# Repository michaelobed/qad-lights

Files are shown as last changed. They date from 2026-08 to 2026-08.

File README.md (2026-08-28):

# Quick-and-Dirty Lights

## What is it?

A quick-and-dirty WiFi-configurable RGB LED driver so I can make my wardrobe all pretty inside.

## Why?

I use RGB LED strips a lot, [as you could probably tell](https://github.com/michaelobed/rgb-switcher), and I can't be bothered with (re)programming an Arduino every time I want to change something subtle, so I bashed something together that lets me change everything I would want to remotely. (I say "bashed", but it took me exactly a week. Oh well!)

## Overview

### Concept

The concept is simple: A microcontroller drives three channels of LEDs, one for red, one for green and one for blue. They either stay on permanently, or turn on when switches are activated in different ways. If you want to change how it operates, you access its web portal and fiddle. That's it!

### Why didn't you build rgb-switcher this way?

Because I am a silly-billy who didn't think that through and thought that retroactively adding web configuration using _an entire other daughterboard_ would be a great idea. Maybe I'll do a v2 rearchitected around the ESP32 when life demands less of me. 😂

### The core system

There isn't much to say on this project really, other than that it's based around the ubiquitous ESP32 chip. It has a decent HAL, simple APIs for key-value storage, WiFi and a HTTP server (not HTTPS for this project - more on that later). Add to that the easy-to-configure PWM driver for LED control and you have a browser-controllable RGB LED driver. Tada! 🎉

### PWM

As I mentioned earlier, this project configures 3 GPIOs as individually controllable PWM outputs, with 8-bit resolution per channel for what is effectively 24-bit colour*. The PWM is actually capable of even more resolution than that, but 8-bit is all the discernible colour difference I need I think. The PWM driver even has built-in hardware fade support, so of course I was going to take advantage of that! It wouldn't have been hard to roll my own if it came down to it, like I did in the hitherto hinted at rgb-switcher project, but it came as a nice surprise.

*: In practice, the resolution is a _lot_ less than that, because big RGB LEDs aren't that great at colour accuracy from experience.

### GPIO

The system currently supports two GPIO inputs, representing reed switches which'll go on my wardrobe doors. It'll turn on when either switch is active or when both switches are active, depending on settings. It also supports both normally open and normally closed orientations.

I normally like to set up switch GPIOs to use the internal pull-up of a microcontroller and connect the other end to GND, but for some really weird reason, that doesn't work here, so I've instead pulled them down and tied the other end to +3V3. It feels icky and perverse, but it works at least.

### WiFi

This is the thing the ESP32 really shines at. It has a built-in 2.4GHz WiFi modem, complete with radio circuitry and, depending on which module you use, often has a built-in ~~antenna~~ aerial 🇬🇧. By default, it boots into access point mode, meaning you connect to _it_ to access its web portal. You can later configure it to connect to your own network for easier access if you so desire.

### HTTP server

This is easily the thing that took the longest, partly because PWM and WiFi are easy and because I really don't do any web coding! I used the actually rather good built-in ESP HTTP Server library, slapped some pages together in HTML and Javascript, then added Websockets support for good measure, so that config changes and RGB sliders all work in realtime.

I almost forgot to mention the lack of HTTP**S** support: I believe you need to supply your own .pem certificate to use that, and for this simple use case that will never see the light of the Internet, I couldn't be bothered with that. It's a good thing to consider, though, especially given that the password to your WiFi network of choice is otherwise supplied over an unencrypted connection in plaintext using the HTTP POST method. A man-in-the-middle attack is possible I suppose, but improbable and impractical, so I'm not too worried.

### Over-the-air firmware updates

The system supports over-the-air firmware updates, or at least firmware updates that don't require you to dismantle your setup and connect a USB cable. For now it's a bit slow and doesn't have per-packet checksumming, so it can fail from time to time, but never in a way that bricks the ESP32 thanks to the implementation of two dedicated OTA partitions.

To use it, navigate to _Update firmware_, then select a .bin file, then click _OK_. If successful, the system will automatically restart and boot from the new firmware image.

### Sleep

The system supports going to sleep when the lights have been off for some period of time to save power. While sleep can be used in setups with normally-closed switches, it isn't recommended as it will contribute to a slightly higher current draw (~15mA more from informal tests).

> [!WARNING]
> The network will not reconnect when waking up from sleep. To have the ESP32 reconnect to the network to allow web configuration, you must use the RESET/EN pin or power cycle it. There will then be a minute-long holdoff period, after which the ESP32 will sleep if there is no web UI connection.

## Final notes

I should point out that I developed this against an ESP-WROOM-32 module sitting on an ESP32-DevKitC board, which is probably really old! I'm sure the code is device-agnostic enough to easily get working on other modules, or even a custom board, but I've done no testing on this. Your mileage may vary, I guess.

I've included a very rough schematic as a guide on how I put this together. I didn't really use a 5V voltage regulator in practice since the dev board was powered via USB for ease of debugging. I pretty much copied the power circuitry from rgb-switcher, and I see no reason for it not to work here given the similar power domain requirements.

I did have a weird issue where the red LED was quite a bit dimmer than green and blue, even after swapping GPIOs around a bit. This ended up being the use of IRF540 mosfets in the end - they barely conduct with the gate-source voltage of 3.3V. I presume the difference in forward voltage of green/blue LEDs vs. red LEDs also contributed to this. I swapped them out for TIP41C darlington BJTs, which I've also used in the past to drive RGB LED strips, though they waste a bit more power doing it from my experience. The fades between the channels are also no longer uniform annoyingly, but at least full white looks white now instead of blue! I didn't get to try the IRF540s with other LED strips, but I'm sure this is a more universal solution than what I had.

As always, I'm releasing this under the MIT license so people can fork the repo, modify the code, sell a product based around it or whatever else. I'm just happy this exists and I can stop writing an entire LED driver when I need one!

## What next?

Since I did bash this together, there are a number of things that are missing or that I'm not completely happy with (in no particular order):

- ~~**Over-the-air firmware update support**. I've provided a partition or two for that, but I've never looked into doing it on the ESP32. It seems simple enough to do, however. Maybe one of you can do it... 😏~~
- **Support for a variable number of switches**. In theory, the logic I have in place makes that feasible, and the `Config` class can easily be extended to allow both the number of switches and their GPIO assignments to be configurable.
- **Make the UI less boring**? This one's more of a maybe since I don't really care that much and just wanted it working, but perhaps a square that changes colours next to the RGB sliders could be cool, albeit more colour accurate than the lights will ever be.
- ~~**Sleep mode**! These should be able to go to sleep when sitting there for ages doing nothing, then wake up and drive the LEDs when the door is opened. This should be easy enough to set up as a wake-up interrupt of some kind.~~
- **Configurable fade time**. This was actually supposed to be in the `Config` class too, but I just haven't gotten around to it.
- **Improve OTA updates**. This is mostly finding ways to increase the chunk size to make updates go faster, as well as adding a per-chunk checksum so we can retry chunks that get corrupted in transit.

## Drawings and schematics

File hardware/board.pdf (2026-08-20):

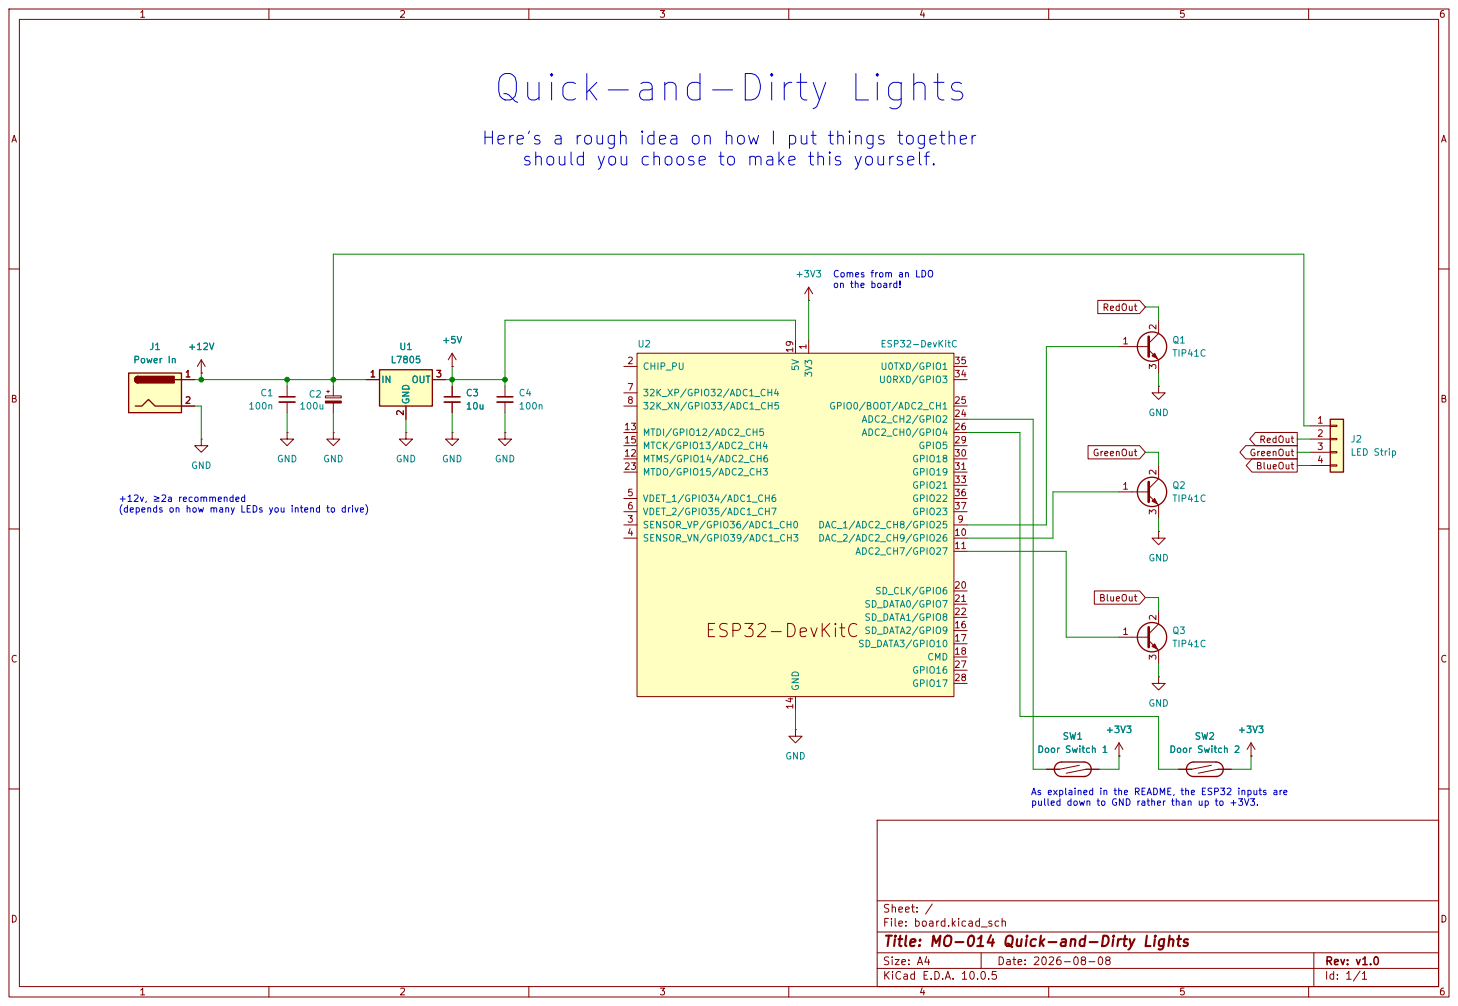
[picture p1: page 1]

Here's a rough idea on how I put things together
should you choose to make this yourself. Comes from an LDO

on the board! +12v, ≥2a recommended

LED Strip +3V3 SW2 Door Switch 2 C2

Sheet: /
File: board.kicad_sch
Title: MO-014 Quick-and-Dirty Lights

Size: A4 | Rev: v1.0
KiCad E.D.A. 10.0.5 | Id: 1/1

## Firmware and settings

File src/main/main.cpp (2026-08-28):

//
//  main.cpp
//  qad-lights
//
//  Created by michaelobed on 29/07/2026.
//  
//  Copyright © 2026 Michael Obed.

#include "Config.hpp"
#include "esp_log.h"
#include "freertos/FreeRTOS.h"
#include "Http.hpp"
#include "Lighting.hpp"
#include "Network.hpp"
#include "Sleep.hpp"
#include "SwitchIO.hpp"
#include "freertos/task.h"
#include "Update.hpp"

static Config& config = Config::GetInstance();
static Http& http = Http::GetInstance();
static Lighting& lighting = Lighting::GetInstance();
static volatile bool lightingState = false;
static volatile bool lightingStateLast = false;
static Network& network = Network::GetInstance();
static Sleep& sleep = Sleep::GetInstance();
static SwitchIO& switchIo = SwitchIO::GetInstance();
static TaskHandle_t switchIOTaskHandle = nullptr;
static Update& update = Update::GetInstance();

static void errorHandler();
static void periodicTask(void* arg);

extern "C" void app_main()
{
    esp_err_t err = ESP_OK;
    bool isSTA = false;

    /* Check for and validate any new OTA images. */
    err = update.Check();
    if(err != ESP_OK)
    {
        ESP_LOGE(__func__, "Could not validate image (%d)!", err);
        errorHandler();
    }

    /* Initialise a default event loop. */
    err = esp_event_loop_create_default();
    if(err != ESP_OK)
    {
        /* We couldn't initialise the default event loop. This is even worse. Freak out! */
        ESP_LOGE(__func__, "Could not init event loop (%d)!", err);
        errorHandler();
    }

    /* Initialise NVS storage. */
    err = config.InitStorage();
    if(err != ESP_OK)
    {
        ESP_LOGE(__func__, "Could not init config storage (%d)!", err);
        errorHandler();
    }

    /* Load the config (or create one if it doesn't exist). */
    err = config.Load();
    if(err != ESP_OK)
    {
        ESP_LOGW(__func__, "Config did not exist or was corrupted. Saving afresh...");
        config.Save();
    }
    else ESP_LOGI(__func__, "Config loaded successfully.");

    /* Initialise switches and create background task. */
    err = switchIo.Configure();
    if(err != ESP_OK)
    {
        ESP_LOGE(__func__, "Could not configure switches (%d)!", err);
        errorHandler();
    }
    xTaskCreate(periodicTask, "SwitchIO", 2048, nullptr, tskIDLE_PRIORITY, &switchIOTaskHandle);

    /* Initialise the lighting driver. */
    err = lighting.Init();
    if(err != ESP_OK)
    {
        ESP_LOGE(__func__, "Could not init lighting driver (%d)!", err);
        errorHandler();
    }

    /* Start the WiFi! */
    isSTA = (config.GetConfigData("networkIsSTA") == 1);
    if(isSTA)
    {
        err = network.InitSTA();
        if(err != ESP_OK)
        {
            ESP_LOGW(__func__, "Could not start WiFi connection to network (%d)! Reverting to access point mode.", err);
            isSTA = false;
        }
        else ESP_LOGI(__func__, "WiFi connection to network started successfully.");
    }

    if(!isSTA)
    {
        err = network.InitAP();
        if(err != ESP_OK)
        {
            ESP_LOGE(__func__, "Could not start WiFi access point (%d)!", err);
            errorHandler();
        }
        else ESP_LOGI(__func__, "WiFi access point started.");
    }

    /* Get HTTP server going. */
    err = http.Init();
    if(err != ESP_OK)
    {
        ESP_LOGE(__func__, "Could not start HTTP server (%d)!", err);
        errorHandler();
    }
    else ESP_LOGI(__func__, "HTTP server started.");

    /* Start a default sleep timer. This won't take effect if we're configured to never sleep. */
    sleep.TimerStartDefault();

    ESP_LOGI(__func__, "Init done! Running main loop...");

    while(true)
    {
        /* Delay so main loop doesn't choke for watchdog reasons. */
        vTaskDelay(100 / portTICK_PERIOD_MS);
    }
}

__noreturn void errorHandler()
{
    /* Do nothing forever. */
    while(true);
}

void Restart()
{
    constexpr uint32_t delayUs = 3000000UL;

    esp_rom_delay_us(delayUs);
    ESP_LOGW(__func__, "*** RESET!!! ***");
    vTaskDelete(switchIOTaskHandle);
    lighting.DeInit();
    if(network.IsRunning())
        network.DeInit();

    esp_restart();
}

void periodicTask(void* arg)
{
    bool lightingStateChanged = false;

    /* Fire every 100ms. */
    while(true)
    {
        /* Handle changes in lighting state based on switch state. */
        lightingState = switchIo.Update();
        lightingStateChanged = (lightingState != lightingStateLast);
        if(lightingStateChanged)
        {
            ESP_LOGI(__func__, "Lighting change detected!");
            lighting.SetState(lightingState);
            lightingStateLast = lightingState;

            /* Start/stop the sleep timer according to the lighting state. */
            if(lightingState)
                sleep.TimerStop();
            else sleep.TimerStart();
        }

        /* Finally, check if we should be sleeping (and sleep if true). */
        sleep.Update();

        vTaskDelay(100 / portTICK_PERIOD_MS);
    }
}

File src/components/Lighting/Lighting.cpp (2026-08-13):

//
//  Lighting.cpp
//  qad-lights
//
//  Created by michaelobed on 29/07/2026.
//  
//  Copyright © 2026 Michael Obed.

#include "Config.hpp"
#include <cstring>
#include "esp_log.h"
#include "Lighting.hpp"

static Config& config = Config::GetInstance();

Lighting::Lighting()
{
    memset(colour, 0xff, 3);
    fadeTimeMsChange = 100;
    fadeTimeMsOn = 500;
    fadeTimeMsOff = 250;
    on = false;
}

void Lighting::DeInit()
{
    ledc_channel_config_t configChannel =
    {
        .gpio_num = -1,                         /* Don't care - we'll change this later. */
        .speed_mode = LEDC_HIGH_SPEED_MODE,
        .channel = LEDC_CHANNEL_MAX,            /* Ditto. */
        .intr_type = LEDC_INTR_FADE_END,
        .timer_sel = LEDC_TIMER_0,
        .duty = 0,
        .hpoint = 0,
        .sleep_mode = LEDC_SLEEP_MODE_NO_ALIVE_NO_PD,
        .flags = 0,
        .deconfigure = true                     /* This is the crucial bit! */
    };
    
    /* Force lights off. */
    doChange(0x00, 0x00, 0x00, 0, false);
    on = false;

    ledc_fade_func_uninstall();

    configChannel.gpio_num = pinR;
    configChannel.channel = LEDC_CHANNEL_0;
    ledc_channel_config(&configChannel);
    configChannel.gpio_num = pinG;
    configChannel.channel = LEDC_CHANNEL_1;
    ledc_channel_config(&configChannel);
    configChannel.gpio_num = pinB;
    configChannel.channel = LEDC_CHANNEL_2;
    ledc_channel_config(&configChannel);

    ESP_LOGI(__func__, "Lighting de-initialised.");
}

void Lighting::doChange(uint8_t r, uint8_t g, uint8_t b, int fadeTime, bool fade)
{
    if(fade)
    {
        ledc_set_fade_with_time(LEDC_HIGH_SPEED_MODE, LEDC_CHANNEL_0, r, fadeTime);
        ledc_set_fade_with_time(LEDC_HIGH_SPEED_MODE, LEDC_CHANNEL_1, g, fadeTime);
        ledc_set_fade_with_time(LEDC_HIGH_SPEED_MODE, LEDC_CHANNEL_2, b, fadeTime);

        ledc_fade_start(LEDC_HIGH_SPEED_MODE, LEDC_CHANNEL_0, LEDC_FADE_NO_WAIT);
        ledc_fade_start(LEDC_HIGH_SPEED_MODE, LEDC_CHANNEL_1, LEDC_FADE_NO_WAIT);
        ledc_fade_start(LEDC_HIGH_SPEED_MODE, LEDC_CHANNEL_2, LEDC_FADE_NO_WAIT);
    }
    else
    {
        ledc_set_duty_and_update(LEDC_HIGH_SPEED_MODE, LEDC_CHANNEL_0, r, 0);
        ledc_set_duty_and_update(LEDC_HIGH_SPEED_MODE, LEDC_CHANNEL_1, g, 0);
        ledc_set_duty_and_update(LEDC_HIGH_SPEED_MODE, LEDC_CHANNEL_2, b, 0);
    }
}

esp_err_t Lighting::Init()
{
    ledc_channel_config_t configChannel =
    {
        .gpio_num = -1,                         /* Don't care - we'll change this later. */
        .speed_mode = LEDC_HIGH_SPEED_MODE,
        .channel = LEDC_CHANNEL_MAX,            /* Ditto. */
        .intr_type = LEDC_INTR_FADE_END,
        .timer_sel = LEDC_TIMER_0,
        .duty = 0,
        .hpoint = 0,
        .sleep_mode = LEDC_SLEEP_MODE_NO_ALIVE_NO_PD,
        .flags = 0,
        .deconfigure = false
    };

    ledc_timer_config_t configTimer =
    {
        .speed_mode = LEDC_HIGH_SPEED_MODE,
        .duty_resolution = LEDC_TIMER_8_BIT,
        .timer_num = LEDC_TIMER_0,
        .freq_hz = 100000,
        .clk_cfg = LEDC_AUTO_CLK,
        .deconfigure = false
    };
    esp_err_t err = ESP_OK;

    /* Configure timer, then configure each channel. */
    err = ledc_timer_config(&configTimer);
    if(err != ESP_OK)
    {
        ESP_LOGE(__func__, "Could not configure lighting timer (%d)!", err);
        return err;
    }

    /* Configure each channel. */
    configChannel.gpio_num = pinR;
    configChannel.channel = LEDC_CHANNEL_0;
    err = ledc_channel_config(&configChannel);

    configChannel.gpio_num = pinG;
    configChannel.channel = LEDC_CHANNEL_1;
    err |= ledc_channel_config(&configChannel);

    configChannel.gpio_num = pinB;
    configChannel.channel = LEDC_CHANNEL_2;
    err |= ledc_channel_config(&configChannel);

    if(err != ESP_OK)
    {
        ESP_LOGE(__func__, "Could not configure one or more lighting channels (%d)!", err);
        return err;
    }

    /* Install fade service. */
    err = ledc_fade_func_install(ESP_INTR_FLAG_LOWMED);
    if(err != ESP_OK)
    {
        ESP_LOGE(__func__, "Could not install fade service (%d)!", err);
        return err;
    }

    SetColour(config.GetConfigData("lightingColour"));
    
    return err;
}

void Lighting::SetColour(uint32_t rgb, bool fade)
{
    colour[0] = (rgb >> 16) & 0xff;
    colour[1] = (rgb >> 8) & 0xff;;
    colour[2] = rgb & 0xff;

    if(on)
        doChange(colour[0], colour[1], colour[2], fadeTimeMsChange, fade);
}

void Lighting::SetState(bool isOn)
{
    on = isOn;
    ESP_LOGI(__func__, "Turning lights %s...", on ? "on" : "off");

    if(on)
        doChange(colour[0], colour[1], colour[2], fadeTimeMsOn, true);
    else doChange(0x00, 0x00, 0x00, fadeTimeMsOff, true);
}

void Lighting::WaitForLEDsOff()
{
    while(  (ledc_get_duty(LEDC_HIGH_SPEED_MODE, LEDC_CHANNEL_0) != 0x00) ||
            (ledc_get_duty(LEDC_HIGH_SPEED_MODE, LEDC_CHANNEL_1) != 0x00) ||
            (ledc_get_duty(LEDC_HIGH_SPEED_MODE, LEDC_CHANNEL_2) != 0x00));
}

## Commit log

2026-07-29 Fix some SDK issues. Pulled Config class from rgb-switcher project, which requires nvs_flash, which requires custom partition table.
    [partitions.csv]
2026-07-29 Amended default sdkconfig. 🥲
2026-07-29 Fixed some project-related oopsies! We have a WiFi AP now with mDNS support. SSID is derived from the chip's MAC address in case many of these are used near each other.
    [main.cpp]
2026-07-29 Employing iterative, error reporting capable, *more scalable* method of config loading.
    [main.cpp]
2026-07-30 We have working Lighting and Http components! 🎉 (I did a quick test with an on and off button outside of source control).
2026-07-31 Managed to get current config data to load when home.html is accessed. It's about time doReplacement() became iterative!
2026-08-01 Got rid of excessive logging now that we know Websockets work. Implemented an option in Lighting::SetColour() to skip fading. I'll still keep it around in case I implement presets so we can fade betw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
    [Lighting.cpp, main.cpp]
2026-08-02 LOTS of Http updates: Name is now hostname, fixed a few unresponsive things. Most importantly, SwitchIO is here to help lights respond to switches!
    [Lighting.cpp, SwitchIO.cpp]
2026-08-02 Fixed styling and back button not working due to me being a JS noob. 🥲
2026-08-04 Overhaul to Config system to make it more easily support metadata (and have dataMap be an arbitrary length that we don't need to keep track of).
2026-08-04 Corrected a few more oopsies in the HTML and hostname change handling. Actually do something with the should-restart-when-config-changes-require-it logic.
    [Lighting.cpp]
2026-08-05 Corrected some HTML inconsistencies with config tags and naming. Brought down warning logs to info logs in de-init code.
    [Lighting.cpp, main.cpp]
2026-08-05 I can't believe I missed that.
    [main.cpp]
2026-08-05 Moved things into a src folder, and finally decided I should probably include dependencies.lock.
    [partitions.csv]
2026-08-05 A little note about my dev board. Also, how on earth did this get here?!
2026-08-05 Added a rough schematic with help from Espressif's KiCad library.
    [board.kicad_pcb, board.kicad_sch]
2026-08-05 It was in the wrong place the whole time. 🙃
2026-08-06 Swapped IRF540Ns for TIP41Cs for weird red LED behaviour reasons.
    [board.kicad_sch]
2026-08-07 Changed LED strip output pins to fix possible issue with bootstrapping on IO0 which I totally should have seen coming.
    [board.kicad_sch]
2026-08-07 #3: Why didn't I do this before?
    [SwitchIO.cpp]
2026-08-07 #3: As well as implementing status text in the UI so I can know when Websockets stop working, we have sleep! It doesn't save much on current draw though... (~350mA -> 287mA)
    [Lighting.cpp]
2026-08-08 #3: Make the italic thing actually work. 😂
2026-08-08 #3: Finally gave the schematic an MO number like my other projects!
    [board.kicad_sch]
2026-08-08 #3: Not even sure if grounding all other I/O helps, but it's prudent I guess?
2026-08-13 #3: Disabled sleep (but kept functions in code in case of future dev).
2026-08-13 Revert "#3: Disabled sleep (but kept functions in code in case of future dev)."
    This reverts commit 7f53f63ee582af76d6c5b3c85c1065dc79d3da34.
    [main.cpp]
2026-08-18 #3: Properly handle switch polarity changes so NC switches can still trigger sleep.
2026-08-19 #3: Put sleepy stuff into its own component since things got a bit complicated. Also added a holdoff timer to allow web UI use at startup with the LEDs on.
2026-08-19 #4: Change to partition table to allow for two OTA FW partitions.
    [partitions.csv]
2026-08-20 Trivial change to correct reference schematic.
    [board.kicad_sch]
2026-08-20 #4: Made a lil' HTML page (currently unhandled in Http class).
2026-08-28 #4: The Lord reminded me to add Base64 encoding to binary payloads. 😂 Chunk sizes need to be smaller though or corruption can still occur.
